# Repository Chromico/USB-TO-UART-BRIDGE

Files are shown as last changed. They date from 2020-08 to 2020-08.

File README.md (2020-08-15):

# USB TO UART BRIDGE REV1

An open source USB to UART converter based on the CH340C IC and designed in KiCad by Tecknologg. The board design and schematic is open source so do whatever you wish with it :)

My website: https://tecknologg.website

# Dimensions 

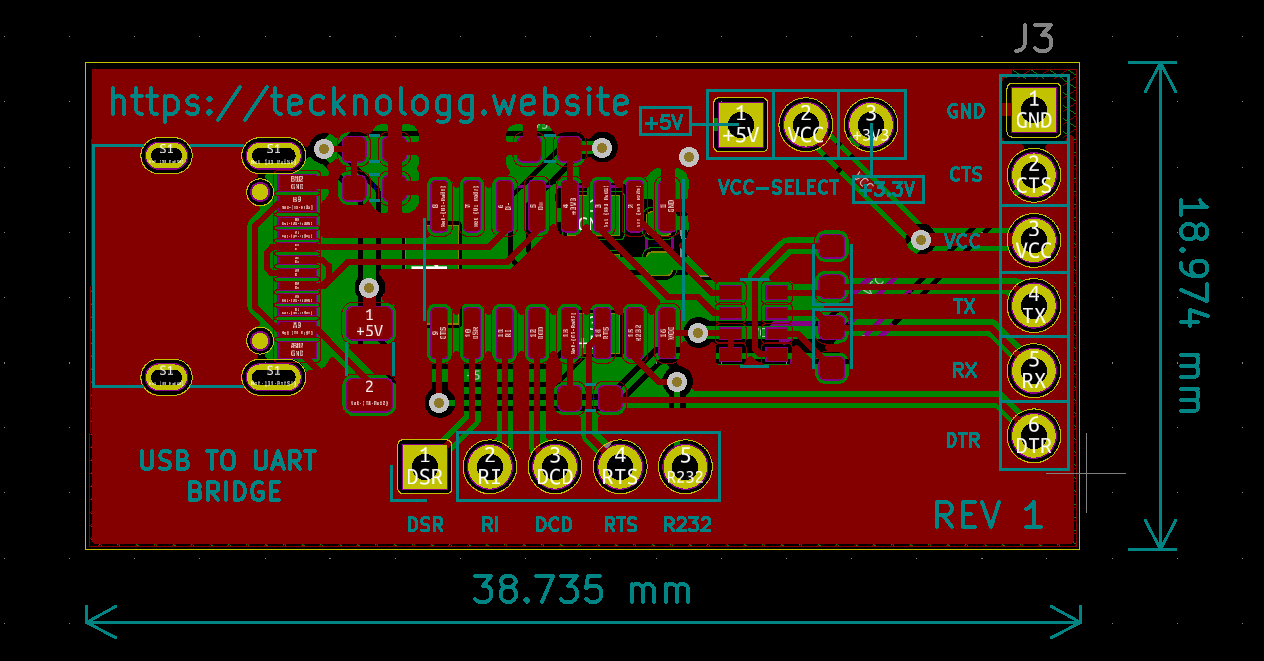
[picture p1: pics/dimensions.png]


# Assembled board

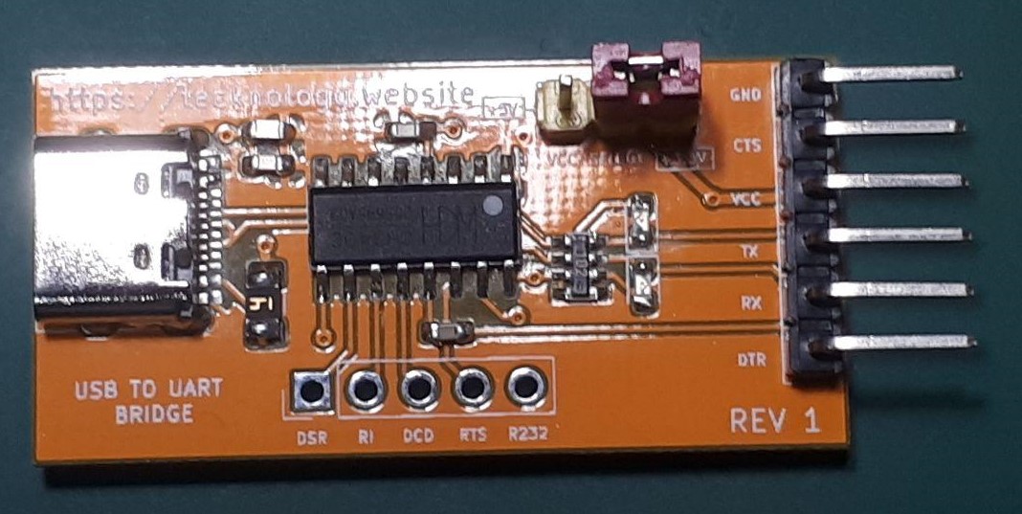
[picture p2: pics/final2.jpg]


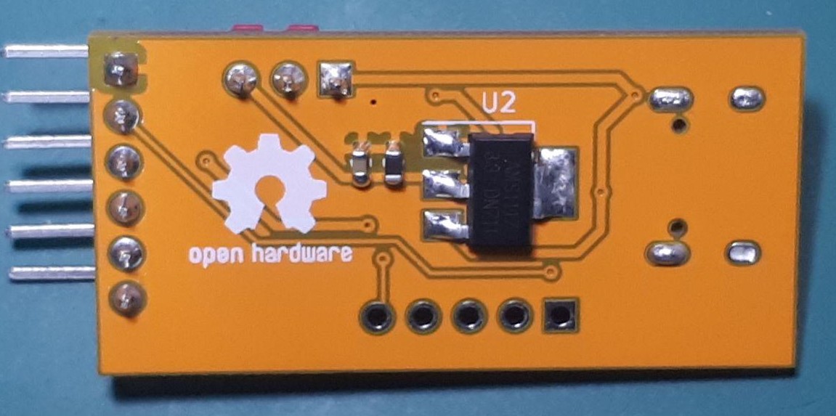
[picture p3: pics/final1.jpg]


# Documentation
You can get the official documentation here: https://github.com/Chromico/USB-TO-UART-BRIDGE/blob/master/docs/CH340C%20USB%20TO%20UART%20BRIDGE%20Documentation.pdf

# Certification
As from 2020, this project is open source hardware certified.

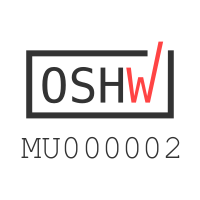
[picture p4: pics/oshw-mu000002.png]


# Contact

Need to contact me ? Just send me an email at nathan@tecknologg.website or tecknologg@gmail.com

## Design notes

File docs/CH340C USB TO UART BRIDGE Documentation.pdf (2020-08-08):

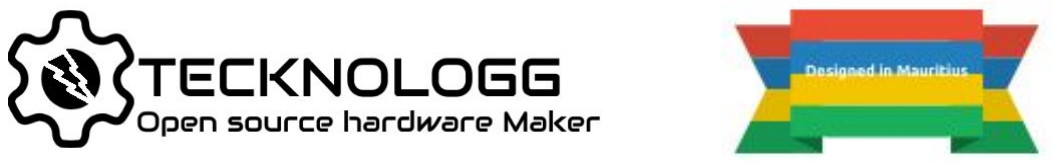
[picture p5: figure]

# CH340C USB TO UART BRIDGE Documentation

August 8, 2020

# Project Overview

The CH340C USB TO UART BRIDGE is a USB to serial converter based on the CH340C IC that can be configured to either work with +3.3V or +5V logic using the VCC SELECT pin headers. It also uses a type C port for the USB connection and has a separate +3.3V voltage regulator.

The project is open-source hardware and designed with KiCad which makes it a lot easier for the user to modify.

Project site where the design files and schematic can be found:

https://github.com/Chromico/USB-TO-UART-BRIDGE

CH340C datasheet:

https://datasheet.lcsc.com/szlcsc/1811111513_WCH-Jiangsu-Qin-Heng-CH340C_C84681.pdf

Official CH340C Drivers from the manufacturer: http://www.wch.cn/downloads/CH341SER_EXE.html

# Final Board Pics

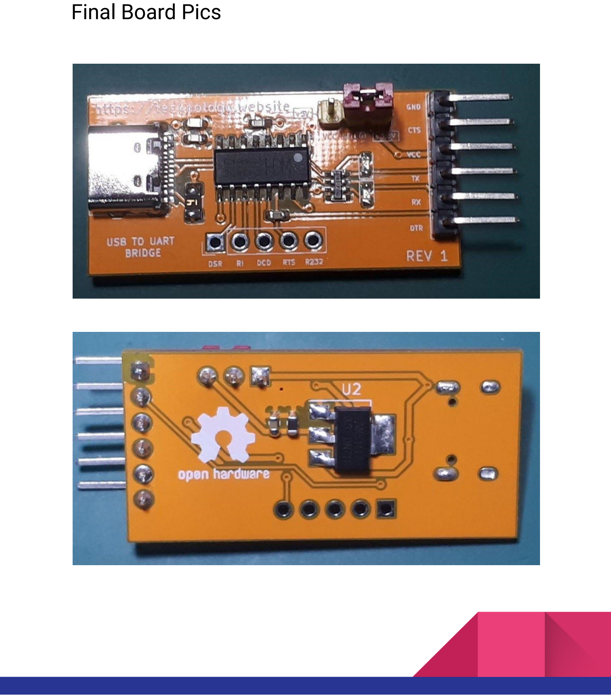
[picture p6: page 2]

# Specifications

- USB Type C connector for communication
- PTC Fuse on USB port power input
- AMS1117 3.3V LDO regulator
- PCB size ( 18.974 mm x 38.735 mm )

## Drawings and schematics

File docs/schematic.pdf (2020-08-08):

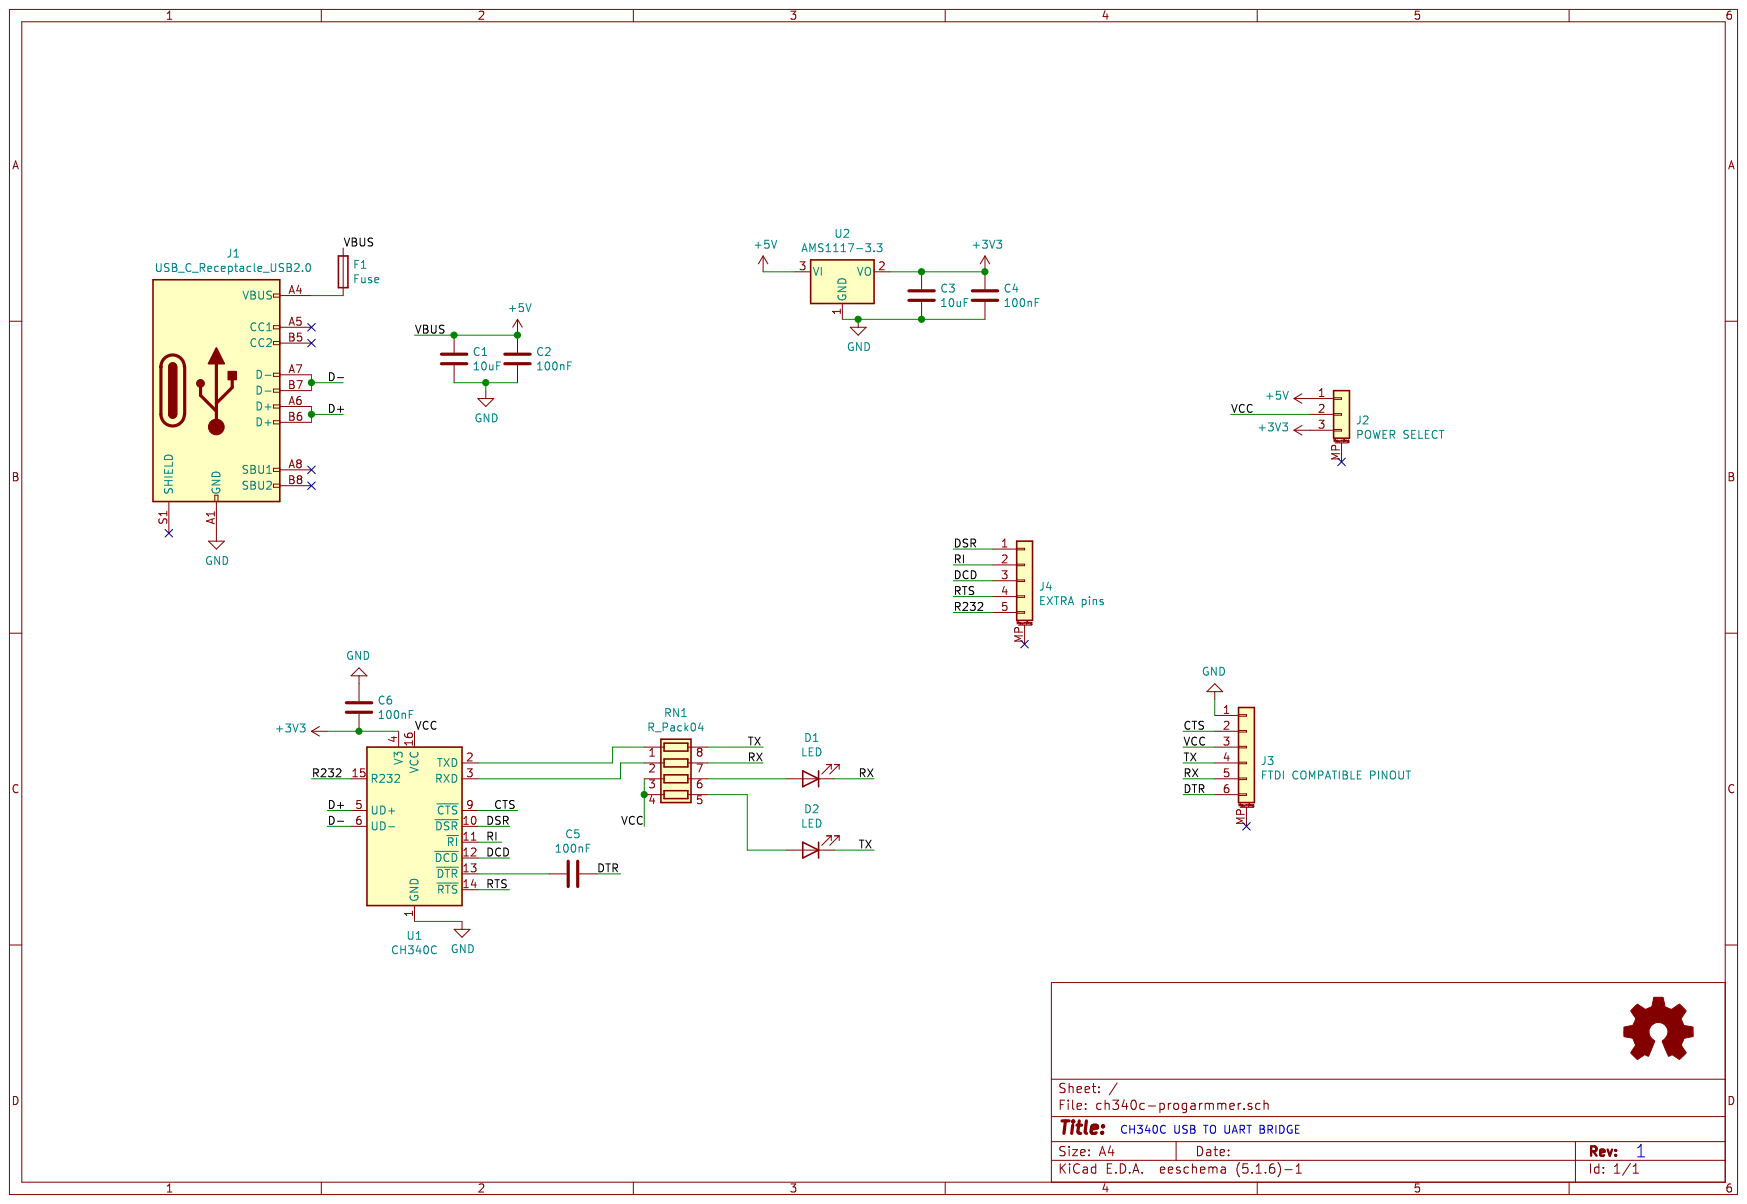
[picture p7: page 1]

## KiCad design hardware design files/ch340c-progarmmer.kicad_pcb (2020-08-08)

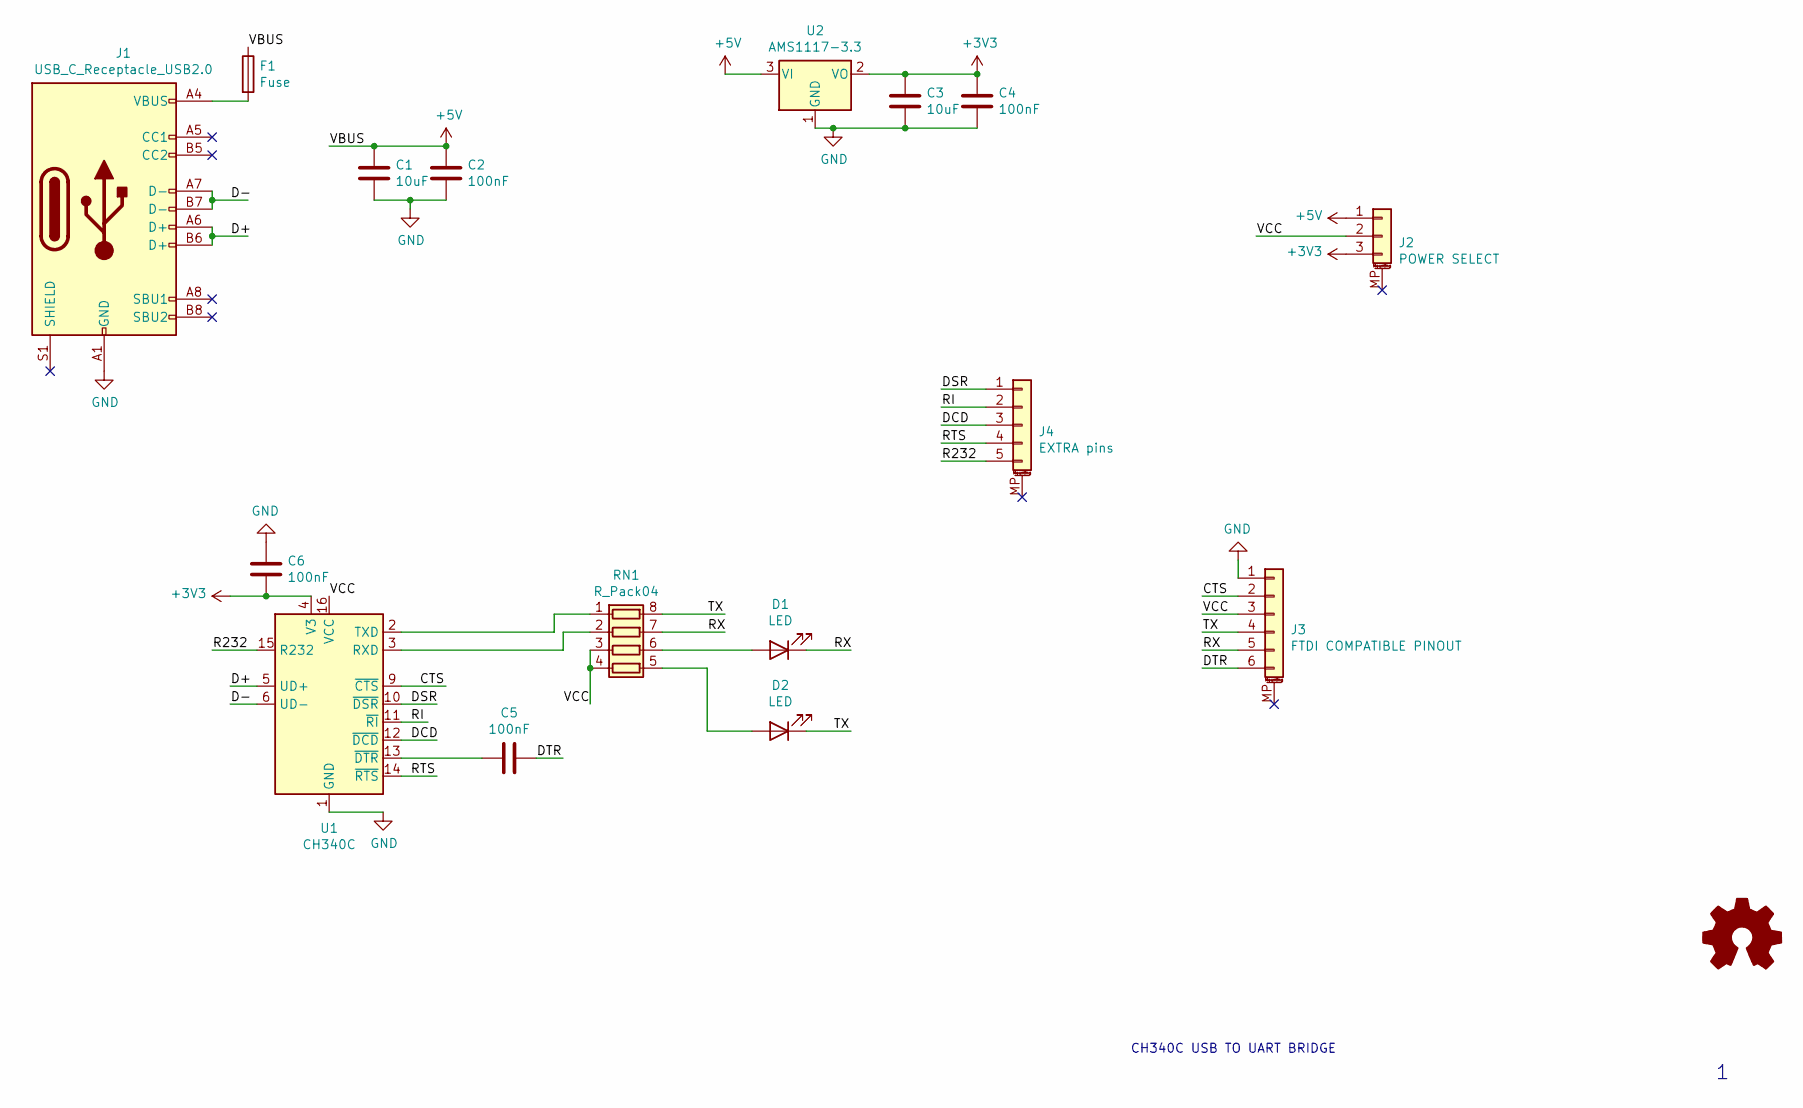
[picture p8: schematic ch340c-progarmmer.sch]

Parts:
C1, C3: 10uF
C2, C4, C5, C6: 100nF
D1, D2: LED
F1: Fuse
J1: USB_C_Receptacle_USB2.0
J2: POWER SELECT
J3: FTDI COMPATIBLE PINOUT
J4: EXTRA pins
RN1: R_Pack04
U1: CH340C; SOIC-16_3.9x9.9mm_P1.27mm
U2: AMS1117-3.3; SOT-223-3_TabPin2

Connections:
+3V3: C3.1, C4.1, C6.2, J2.3, U1.4 (V3), U2.2 (VO)
+5V: C1.1, C2.1, F1.1, J2.1, U2.3 (VI)
/CTS: J3.2, U1.9 (~CTS)
/D+: J1.A6 (D+), J1.B6 (D+), U1.5 (UD+)
/D-: J1.A7 (D-), J1.B7 (D-), U1.6 (UD-)
/DCD: J4.3, U1.12 (~DCD)
/DSR: J4.1, U1.10 (~DSR)
/DTR: C5.1, J3.6
/R232: J4.5, U1.15 (R232)
/RI: J4.2, U1.11 (~RI)
/RTS: J4.4, U1.14 (~RTS)
/RX: D1.1 (K), J3.5, RN1.7 (R2.2)
/TX: D2.1 (K), J3.4, RN1.8 (R1.2)
/VCC: J2.2, J3.3, RN1.3 (R3.1), RN1.4 (R4.1), U1.16 (VCC)
GND: C1.2, C2.2, C3.2, C4.2, C6.1, J1.A1 (GND), J1.A12 (GND), J1.B1 (GND), J1.B12 (GND), J3.1, U1.1 (GND), U2.1 (GND)
unnamed: C5.2, U1.13 (~DTR)
unnamed: D1.2 (A), RN1.6 (R3.2)
unnamed: D2.2 (A), RN1.5 (R4.2)
unnamed: F1.2, J1.A4 (VBUS), J1.A9 (VBUS), J1.B4 (VBUS), J1.B9 (VBUS)
unnamed: RN1.1 (R1.1), U1.2 (TXD)
unnamed: RN1.2 (R2.1), U1.3 (RXD)

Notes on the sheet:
CH340C USB TO UART BRIDGE

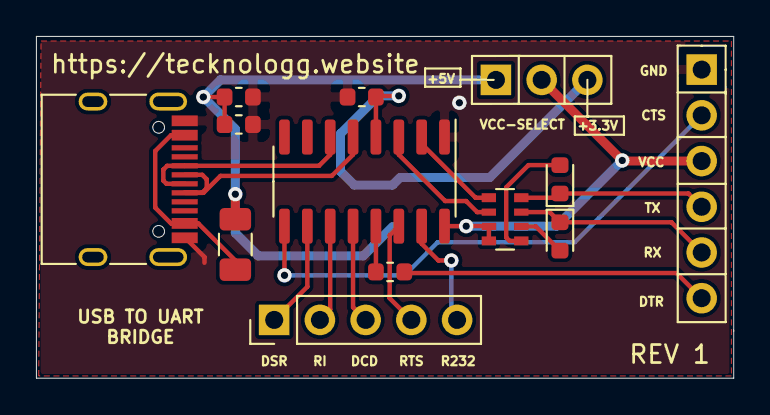
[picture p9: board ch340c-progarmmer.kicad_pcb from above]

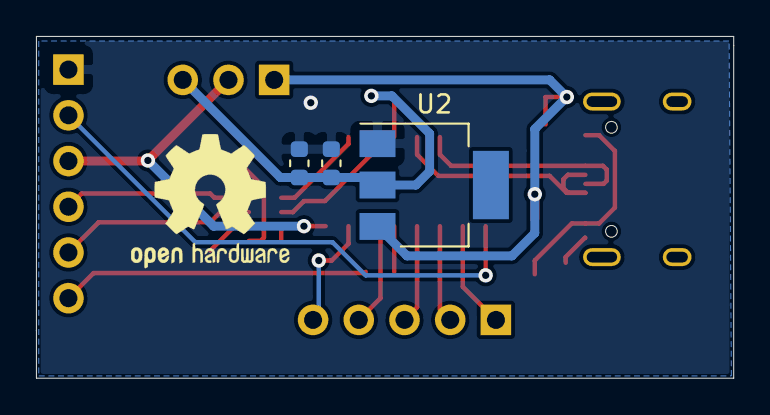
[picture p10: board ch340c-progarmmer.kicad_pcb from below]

Board: 2 copper layers, 38.7 x 19.0 mm, 16 parts (3 on the bottom side), 21 nets.
